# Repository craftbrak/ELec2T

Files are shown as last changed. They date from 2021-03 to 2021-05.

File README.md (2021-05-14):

# ELec2T

lien du raport intermediaire : https://docs.google.com/document/d/1l9kerCUgm6wP6RkYXObC0R5gBAUdyCEyKLtMM8cPomE/edit?usp=sharing

lien du cahier des charges : /

lien du Trello: https://trello.com/b/0pvsDK53/main

lien du rapport final https://docs.google.com/document/d/1BPvHGJe16M144FmVLOqQ-wgt9hW2KqvDGt-wu0VLWqM/edit#

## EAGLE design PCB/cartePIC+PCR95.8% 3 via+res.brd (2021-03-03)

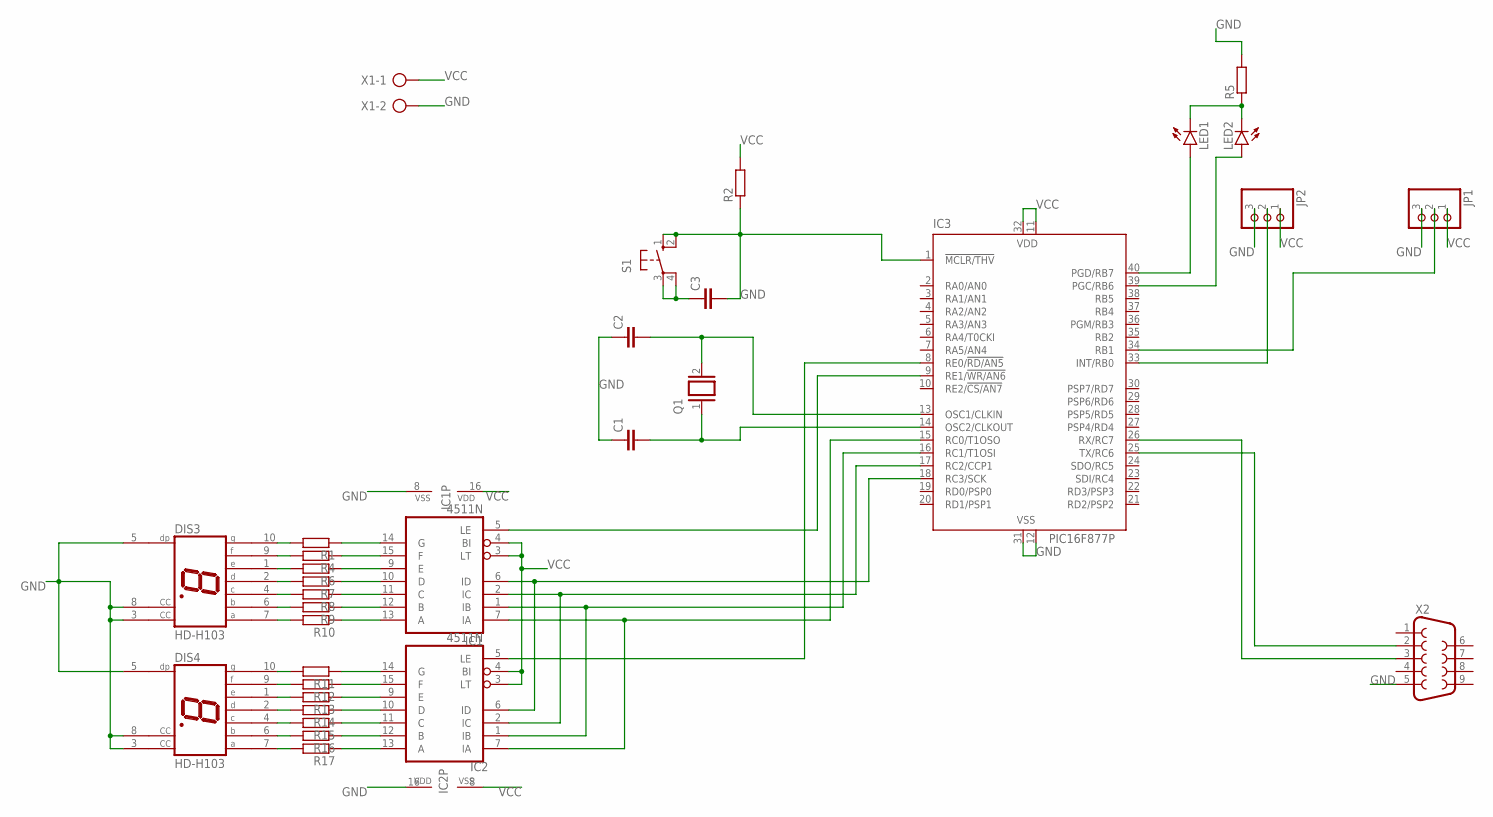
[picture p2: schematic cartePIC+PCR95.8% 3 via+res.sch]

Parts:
C1, C2, C3: C-EU025-025X050; C025-025X050
DIS3, DIS4: HD-H103; HDSP-M
IC1, IC2: 4511N; DIL16
IC3: PIC16F877P; DIL40
JP1, JP2: PINHD-1X3; 1X03
LED1, LED2: LED5MM
Q1: XTAL/S; QS
R1, R2, R4, R5, R6, R7, R8, R9, R10, R11, R12, R13, R14, R15, R16, R17: R-EU_0207/10; 0207/10
S1: 10-XX; B3F-10XX
X1: AK300/2
X2: F09H

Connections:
GND: C1.1, C2.1, C3.2, DIS3.3 (CC), DIS3.5 (DP), DIS3.8 (CC), DIS4.3 (CC), DIS4.5 (DP), DIS4.8 (CC), IC1.8 (VSS), IC2.16 (VDD), IC3.1 (!MCLR/THV), IC3.12 (VSS), IC3.31 (VSS), JP1.3, JP2.3, R2.1, R5.2, S1.1 (S), S1.2 (S1), X1.2, X2.5
unnamed: IC1.5 (LE), IC3.9 (RE1/!WR/AN6)
unnamed: IC2.5 (LE), IC3.8 (RE0/!RD/AN5)
unnamed: IC1.6 (ID), IC2.6 (ID), IC3.18 (RC3/SCK)
unnamed: IC1.2 (IC), IC2.2 (IC), IC3.17 (RC2/CCP1)
unnamed: IC1.1 (IB), IC2.1 (IB), IC3.16 (RC1/T1OSI)
unnamed: IC1.7 (IA), IC2.7 (IA), IC3.15 (RC0/T1OSO)
unnamed: C2.2, IC3.13 (OSC1/CLKIN), Q1.2
unnamed: C1.2, IC3.14 (OSC2/CLKOUT), Q1.1
unnamed: IC1.14 (G), R1.1
unnamed: IC1.15 (F), R4.1
unnamed: IC1.9 (E), R6.1
unnamed: IC1.10 (D), R7.1
unnamed: IC1.11 (C), R8.1
unnamed: IC1.12 (B), R9.1
unnamed: IC1.13 (A), R10.1
unnamed: IC2.14 (G), R11.1
unnamed: IC2.15 (F), R12.1
unnamed: IC2.9 (E), R13.1
unnamed: IC2.10 (D), R14.1
unnamed: IC2.11 (C), R15.1
unnamed: IC2.12 (B), R16.1
unnamed: IC2.13 (A), R17.1
unnamed: IC3.33 (INT/RB0), JP2.2
unnamed: C3.1, S1.3, S1.4 (P1)
unnamed: IC3.34 (RB1), JP1.2
unnamed: IC3.40 (PGD/RB7), LED1.A
unnamed: IC3.25 (TX/RC6), X2.2
unnamed: IC3.26 (RX/RC7), X2.3
unnamed: IC3.39 (PGC/RB6), LED2.A
unnamed: LED1.K (C), LED2.K (C), R5.1
unnamed: DIS3.10 (G), R1.2
unnamed: DIS3.9 (F), R4.2
unnamed: DIS3.1 (E), R6.2
unnamed: DIS3.2 (D), R7.2
unnamed: DIS3.4 (C), R8.2
unnamed: DIS3.6 (B), R9.2
unnamed: DIS3.7 (A), R10.2
unnamed: DIS4.10 (G), R11.2
unnamed: DIS4.9 (F), R12.2
unnamed: DIS4.1 (E), R13.2
unnamed: DIS4.2 (D), R14.2
unnamed: DIS4.4 (C), R15.2
unnamed: DIS4.6 (B), R16.2
unnamed: DIS4.7 (A), R17.2
VCC: IC1.3 (LT), IC1.4 (BI), IC1.16 (VDD), IC2.3 (LT), IC2.4 (BI), IC2.8 (VSS), IC3.11 (VDD), IC3.32 (VDD), JP1.1, JP2.1, R2.2, X1.1

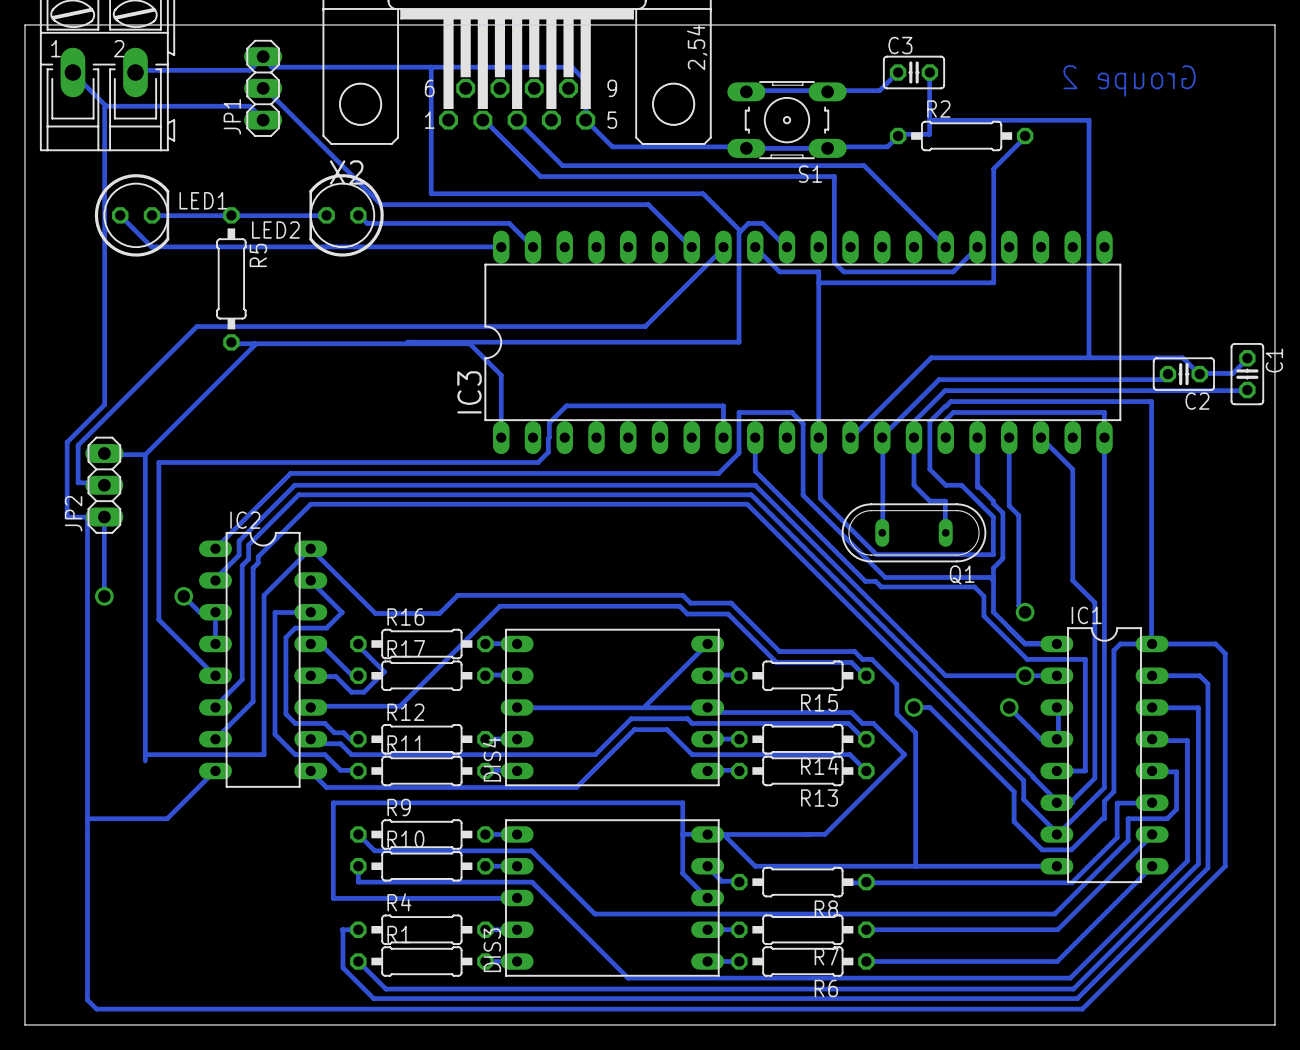
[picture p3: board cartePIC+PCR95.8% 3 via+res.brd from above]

Board: 2 copper layers, 100.0 x 80.0 mm, 32 parts (0 on the bottom side), 46 nets.

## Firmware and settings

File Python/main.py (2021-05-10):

import serial
import threading

from kivy.app import App
from kivy.uix.button import Button
from kivy.uix.label import Label
from kivy.uix.image import Image
from kivy.uix.boxlayout import BoxLayout
from kivy.uix.textinput import TextInput
from kivy.core.window import Window

FLAG_RESET = 1
FLAG_RESEND = 2
FLAG_SET_MAX = 4


class MyApp(App):
    def __init__(self, **kwargs):
        super().__init__(**kwargs)
        self.port = serial.Serial('COM3')
        self.running = True
        self.people = 0
        self.max_people = 0

        #Précharge les images
        Image(source='vert.png')
        Image(source='rouge.png')

        self.thread = threading.Thread(target=self.read)
        self.thread.start()

    def on_request_close(self, *args):
        self.running = False
        self.port.close()
        self.thread.join()
        return False

    def read(self):
        self.write(FLAG_RESEND)
        while self.running:
            buf = self.port.read(3)
            if buf:
                flags, people, max_people = buf
                self.image.source = 'rouge.png' if flags else 'vert.png'
                self.people = people
                self.max_people = max_people
                self.label_actuel.text = f"Il y a {self.people} personnes dans le magasin !"
                self.label_limite.text = f"La limite du magasin est de {self.max_people} personnes !"
                print(f'recv {flags=} {people=} {max_people=}')

    def write(self, flags, max_people=0):
        self.port.write(bytes([flags, max_people]))

    def set_max_people(self, max_people):
        self.write(FLAG_SET_MAX | FLAG_RESEND, max_people)

    def send_reset(self):
        self.write(FLAG_RESET)

    def build(self):
        self.afficheur = BoxLayout(orientation='vertical')

        self.afficheur.add_widget(Label(text="A combien de personnes voulez-vous limiter l'accès ?"))

        self.nombre_client = TextInput(text="", input_type='number')
        self.afficheur.add_widget(self.nombre_client)

        self.boutton = Button(text="Définir nombre client")
        self.boutton.bind(on_press=self.voir)
        self.afficheur.add_widget(self.boutton)

        self.label_limite = Label(text=f"La limite du magasin est de {self.max_people} personnes")
        self.afficheur.add_widget(self.label_limite)

        self.label_actuel = Label(text=f"Il y a {self.people} personnes dans le magasin !")
        self.afficheur.add_widget(self.label_actuel)

        layout = BoxLayout(orientation='horizontal')
        button = Button(text='Reset')
        button.bind(on_press=lambda *a: self.send_reset())
        self.image = Image(source='vert.png')
        layout.add_widget(self.image)
        layout.add_widget(button)
        self.afficheur.add_widget(layout)

        Window.bind(on_request_close=self.on_request_close)

        return self.afficheur

    def voir(self, text):
        nombre = self.nombre_client.text.strip()
        if nombre == "":
            print("False")
        elif not nombre.isnumeric():
            print("Ce n'est pas un nombre !")
            self.label_limite.text = "Ce n'est pas un nombre !"
        else:
            self.set_max_people(int(self.nombre_client.text))


if __name__ == '__main__':
    MyApp().run()

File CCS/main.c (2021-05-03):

#include "common.h"

int flag_add = 0;
int flag_sub = 0;
int flag_data = 0;

char buffer[BUFFER_SIZE];

int max_people = 5;

#int_EXT
void  EXT_isr(void)
{
   flag_add = 1;
}

#int_EXT1
void  EXT1_isr(void)
{
   flag_sub = 1;
}

#int_RDA
void  RDA_isr(void)
{
   int i = 0;
   flag_data = 1;
   //for (i = 0; kbhit() && i < BUFFER_SIZE; ++i) {
   do {
     buffer[i++] = getc();
   } while (i < BUFFER_SIZE);
   output_d(i);
}

void send(int armed, int people, int max_people) {
   // printf("%c%c%c", (char) armed, (char) people, (char) max_people);
   putc((char) armed);
   putc((char) people);
   putc((char) max_people);
}

void display(int value) {
   int unit, ten;
   unit = ((value / 10) % 10) & 0xf;
   ten  = (value % 10) & 0xf;

   output_high(PIN_E0);
   output_low(PIN_E1);

   //output_c(((value / 10) % 10) & 0xf);
   output_bit(PIN_C0, (unit >> 0) & 1);
   output_bit(PIN_C1, (unit >> 1) & 1);
   output_bit(PIN_C2, (unit >> 2) & 1);
   output_bit(PIN_C3, (unit >> 3) & 1);


   output_high(PIN_E1);
   output_low(PIN_E0);

   //output_c((value % 10) & 0xf);
   output_bit(PIN_C0, (ten >> 0) & 1);
   output_bit(PIN_C1, (ten >> 1) & 1);
   output_bit(PIN_C2, (ten >> 2) & 1);
   output_bit(PIN_C3, (ten >> 3) & 1);

   output_high(PIN_E1);
   output_high(PIN_E0);
}

void main()
{
   int people = 0;
   int armed = 0;
   int last = 0;
   int flags;

   setup_adc_ports(NO_ANALOGS);
   setup_adc(ADC_OFF);
   setup_psp(PSP_DISABLED);
   setup_spi(SPI_SS_DISABLED);
   setup_wdt(WDT_OFF);
   setup_timer_0(RTCC_INTERNAL);
   setup_timer_1(T1_DISABLED);
   setup_timer_2(T2_DISABLED,0,1);
   setup_comparator(NC_NC_NC_NC);
   setup_vref(FALSE);
   enable_interrupts(INT_EXT);
   enable_interrupts(INT_EXT1);
   enable_interrupts(INT_RDA);
   enable_interrupts(GLOBAL);
   //set_tris_c(0x80);
//Setup_Oscillator parameter not selected from Intr Oscillotar Config tab

   send(armed, people, max_people);
   for (;;) {
      if (flag_add) {
         flag_add = 0;
         ++people;
      }
      if (flag_sub) {
         flag_sub = 0;
         if (people > 0)
            --people;
      }
      if (flag_data) {
         flag_data = 0;
         flags = (int) buffer[0];
         //output_d(flags);

         if (flags & FLAG_SET_MAX)
            max_people = buffer[1];

         if (flags & FLAG_RESEND)
            send(armed, people, max_people);

         if (flags & FLAG_RESET)
            people = 0;
      }

      armed = people >= max_people;
      if (armed) {
         output_low(PIN_B7);
         output_toggle(PIN_B6);
      } else {
         output_low(PIN_B6);
         output_high(PIN_B7);
      }

      if (last != people) {
         last = people;
         display(people);
         send(armed, people, max_people);
      }

      delay_ms(200);
   }

}

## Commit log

2021-02-17 ajout des composant
2021-02-17 test c + circuit
2021-02-27 update sim +PCB
2021-02-27 final PCB
    [Groupe 2 final PCB.brd, Groupe 2 final PCB.sch]
2021-02-27 correction erreur nom groupe + vertion avec resistance
    [cartePIC+PCR95.8% 3 via+res.brd, cartePIC+PCR95.8% 3 via+res.sch]
2021-02-28 Final Board
    [Groupe 2 final PCB.brd, Groupe 2 final PCB.sch]
2021-03-12 added connector for alarm on the board
2021-05-02 python threading not finished
2021-05-03 Fix RDA conflict with display
    [main.c]
